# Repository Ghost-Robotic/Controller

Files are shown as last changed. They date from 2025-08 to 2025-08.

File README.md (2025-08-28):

# 3D printed multipurpose Controller

## About
This is a 3D printed controller designed primarily to be used in robotics to control things such as robotic arms. The idea to create this came after I designed and built my own robotic arm using a couple of servos and an arduino. However, controlling the robotic arm was hard, movement was janky, the arduino was not able to solve the complex inverse kinematics needed for higher DOF and the most annoying thing was that I was controlling the arm using two joysticks hotglued onto a carboard box while physically connected to the robotic arm with a cable. This is why I decided to design and 3D printer a better wireless controller with a sleek and proffessional looking designed inspired by other gamepads. 

With two joysticks, buttons, accelerometer and pots, this controller is able to allow for the control complex movement of robotic arms while offering options for different keybinds for automated movements. The large colour screen, leds and buzzer allow for a large variety of information to be displayed to the user in a format that is accessible and allows for key information to be distinct.

However, what if you want to play some games? There is planned support for intergrating simple games into the controller that can be displayed on the screen and use the large variety of control methods available. For example playing the dino game using the accelerometer by physically jumping. 

The overall goal for the controller is to be modular with support for a variety of functions and can be quickly adapted for different applications.

## CAD
https://cad.onshape.com/documents/7b6b5bf345c0989f6e254701/w/9353e7d330a39dfe5d969377/e/e7967eaf3d01a9f44c40f175

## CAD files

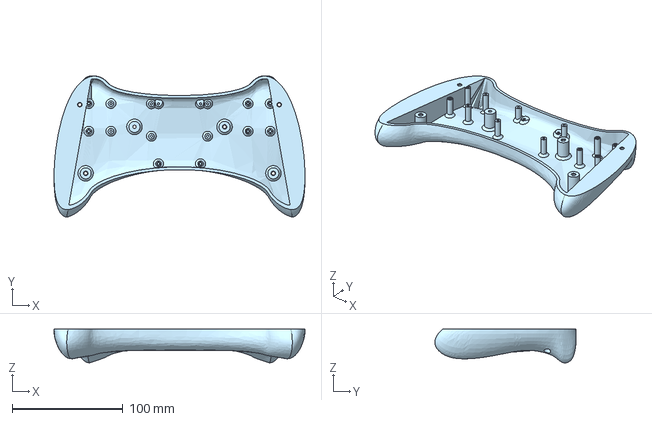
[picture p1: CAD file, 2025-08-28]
STEP files/3D printed multipurpose Controller- Bottom.step
226.6 x 127.6 x 30.5 mm

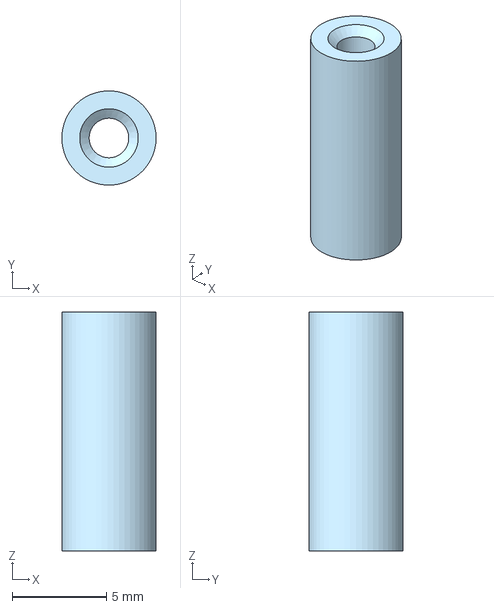
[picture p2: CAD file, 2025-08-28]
STEP files/3D printed multipurpose Controller- spacer2.step
5.00 x 5.00 x 12.7 mm

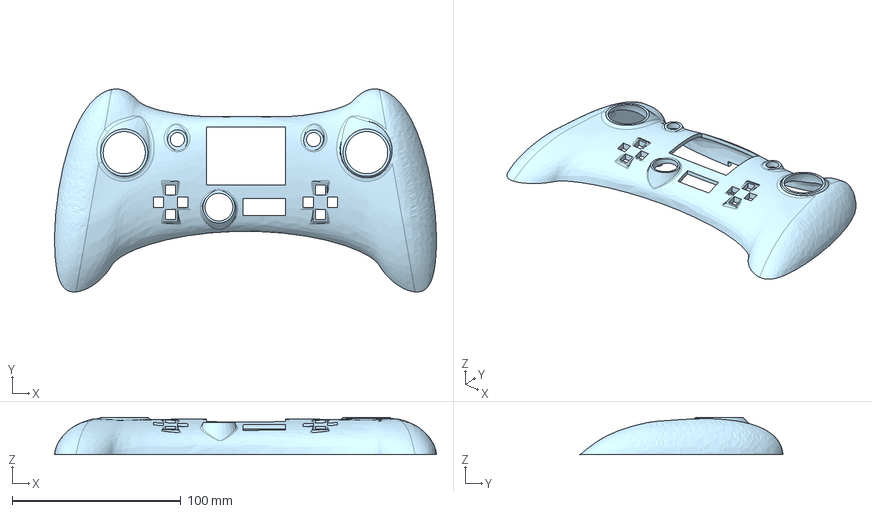
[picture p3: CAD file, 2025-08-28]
STEP files/3D printed multipurpose Controller- Top.step
226.6 x 120.4 x 22.2 mm

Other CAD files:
STEP files/3D printed multipurpose Controller- spacer3.step
STEP files/3D printed multipurpose Controller- spacer4.step
STEP files/3D printed multipurpose Controller- spacer1.step

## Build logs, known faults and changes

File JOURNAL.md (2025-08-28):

---
Title: "Controller"
Author: "Nithling"
Description: "A custom 3D printed controller"
Created On: "13/08/2025"
---

# August 13th: Creating the profile sketches!

Created the profile sketches for the side and top of the controller grips using splines. Then experimented in adding additional splines along the length of the grips to try loft the entire grip.




**Total time spent: 3.5h**

# August 14th: Finished hand grips

Remade the wireframe for the grips using 3d splines and lofted the surfaces to make a solid object that will be the hand grips. This took a lot of trial and error.



**Total time spent: 3hr**

# August 15th: Redid hand grips
Once again I redid how I lofted the grips, I instead used two lofts instead of 4 and used fewer curves as guides to create a more natural shape. I also angled the grips away from the centre which took a lot of trial and error as well as redoing many of the sketches as they kept breaking due to some geometry being defined weirdly.




**Total time spent: 3hr**

# August 16th: Sketching rest of body
Drew the sketches for the rest of the body



**Total time spent: 15min**

# August 24th: Faliure
Made a crude loft for the centre of the body but discovered that I was not able to shell the hand grips. Spent several hours trying to change the geometry of the grips to be able to be shelled  but was not able to. In the end I had to just leave part of the grip solid and try to fit the electronics around it.



**Total time spent: 4hr**

# August 25th: Adding Electronics
Started sketching out all the locations for the electronics and other components. Not physically having the components made it much more difficult to plan where they would go as I was not able to see how they would fit together. This was further complicated by the fact that many of the components do not have proper documentation for their dimensions. I also decided to mount the pico and some other items like the buzzer and accelerometer on veraboard as it gave me more flexbility in how I could place componenents. I also began extruding the mounts for some of the components which was difficult as the surface of the controller was not flat and was instead curved and also on an angle. This was particuarly hard for the mounting of the joystick as I had no physical model or drawings to work with and creating the correct holes that would fit the joystick(ended up guestimating). Creating the geometry for the holes was also very difficult and took a lot of trial and error. (second time writing this :(, forgot to commit edits)




**Total time spent: 4hr**

# August 26th: more of ^^^^
Continued creating the mounting for the electronics such as finalising the mounting point for the joysticks, the power button and creating a hole for micro usb cable for the pico. Smoothed out some of the mounting points on the top surface using drafts and fillets. Next step is to create the holes to connect the two halves together





**Total time spent: 2hr**

# August 27th: Finalising Design
Added the holes to connect the two halves of the controller together. Added chamfers on the various mounting posts to help ensure they do not snap off as well as chamfers on the holes to aid in getting screws into the part. I searched for a bit(some of the total time includes finding suitable components that I could use) to find a LiPo battery charger that I could add to the pico so that i can charge the LiPo without removing it from the case. I did some calculations to determine that if the pico w drew around 100mA, a 200mah LiPo battery should be able to power it for 2hr however without knowing the current draw of thhe other periphals this would likely be less.





with auto supports will prob be less with manual support

**Total time spent: 2hr**

BOM:

1x Rasberry Pi Pico W

* 2x Joystick https://www.amazon.com/HiLetgo-Controller-JoyStick-Breakout-Arduino/dp/B00P7QBGD2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

* 1x accelerometer https://www.amazon.com/HUAREW-MPU6050-Gyroscope-Accelerometer-Converter/dp/B0CRVR1P66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

* 8x small buttonhttps://www.amazon.com/DAOKI-Miniature-Momentary-Tactile-Quality/dp/B01CGMP9GY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

* 1x buzzer https://www.amazon.com/mxuteuk-Electronic-Computers-Printers-Components/dp/B07VK1GJ9X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

* 1x segment led display https://www.amazon.com/Bestol-Segment-Digital-Display-Bright/dp/B07F11P2X9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

* 2x pot https://www.amazon.com/DIYhz-Rotary-Encoder-Digital-Potentiometer/dp/B07D3DF8TK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

* 1x 1.8 screen https://www.digikey.com/en/products/detail/adafruit-industries-llc/358/5801368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

* 1x analog/digital breakout https://www.sparkfun.com/sparkfun-analog-digital-mux-breakout-cd74hc4067.html or https://www.adafruit.com/product/5836?srsltid=AfmBOopbR_FtnUanDIy2z5l5viOq5bFq5tQ5RCXxs68W7XwBSWc96bWj

* 1x Power button https://www.aliexpress.com/item/1005006090350341.html?

* 1x pi pico header kit https://core-electronics.com.au/header-kit-for-raspberry-pi-pico.html

* 1x veraboard https://www.jaycar.com.au/pc-boards-vero-type-strip-95-x-152mm/p/HP9542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
  
* 1x solid core wire https://core-electronics.com.au/hook-up-wire-spool-black-25-ft.html
  
* 1x EYESPI breakout and cable for  1.8screen https://www.adafruit.com/product/5613 https://www.adafruit.com/product/5239

* 1x LiPo battery https://www.auselectronicsdirect.com.au/rechargeable-li-po-battery-3.7v-200mah-for-nh010-t

* 1x LiPo battery charger https://core-electronics.com.au/pimoroni-lipo-shim-for-pico.html
